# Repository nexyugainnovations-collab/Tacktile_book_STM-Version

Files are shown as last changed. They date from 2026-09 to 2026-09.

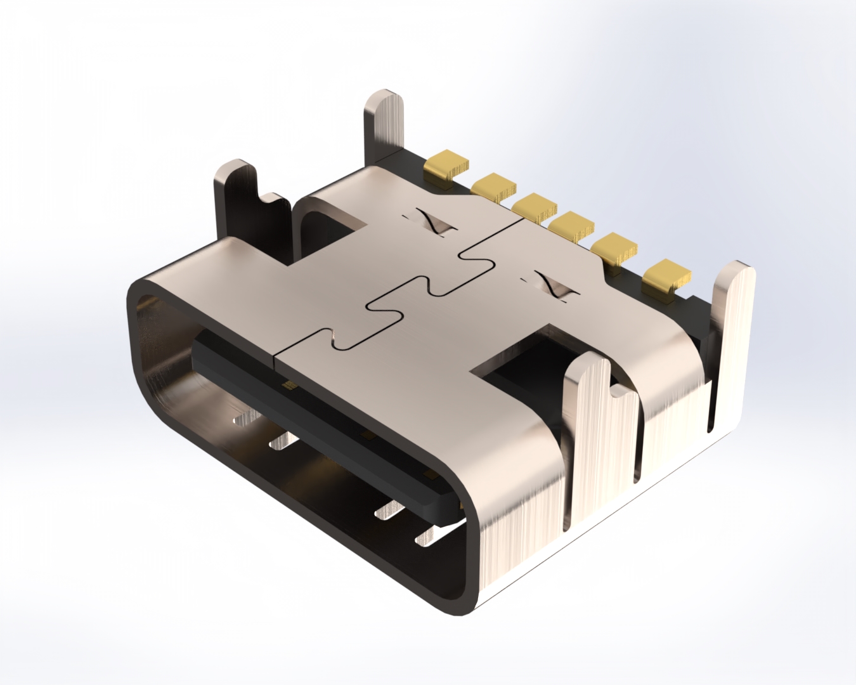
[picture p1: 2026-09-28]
3D models/USB Connector Type C female 6pin/USB Connector Type C female 6pin.jpg

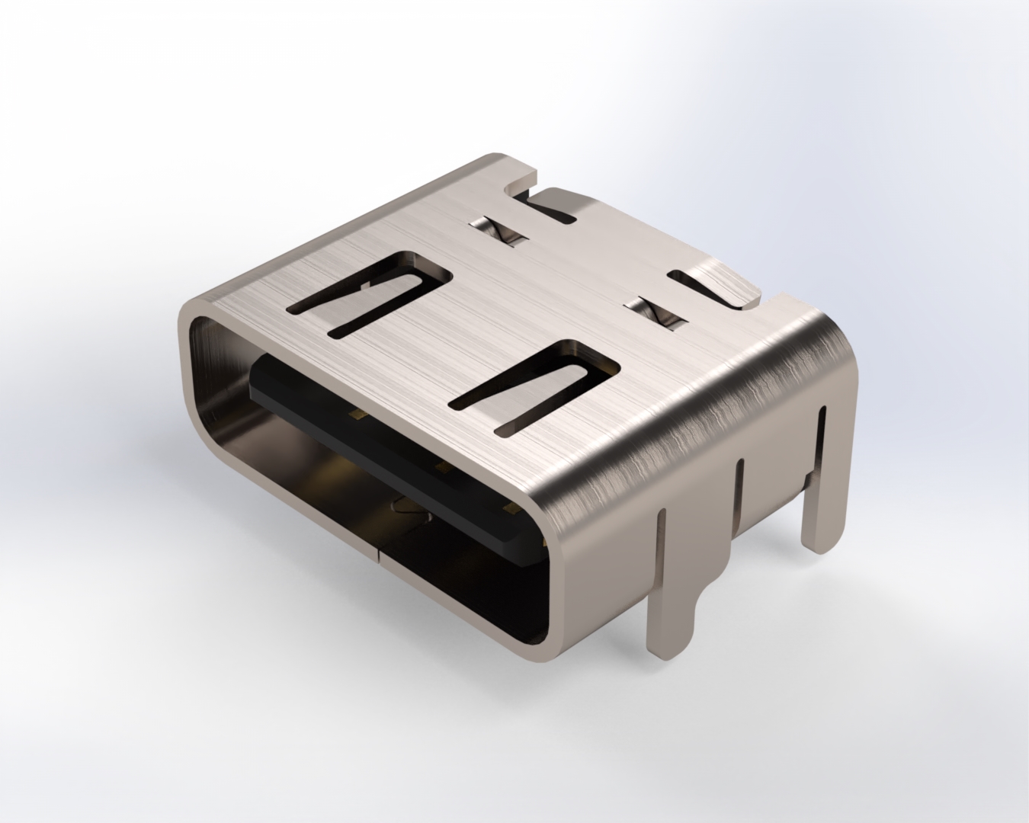
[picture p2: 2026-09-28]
3D models/USB Connector Type C female 6pin/USB Connector Type C female 6pin (2).jpg

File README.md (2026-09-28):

# Tacktile Book STM (v1.0)

STM32-based hardware design for the Tacktile book, an interactive tactile book that plays audio in response to touch. This repository contains the PCB design files and the audio content used by the device.

Developed by **Nexyuga Innovations**.

## Contents

| Folder | Description |
|---|---|
| pcb/ | Schematic and board layout source files |
| gerber/ | Fabrication outputs (Gerbers, drill files) |
| bom/ | Bill of materials |
| audio/ | Audio files used by the device |
| docs/ | Datasheets, notes and images |

Folder names may differ slightly from the actual layout. Update the table to match the repository.

## Hardware

- **Microcontroller:** STM32 (part number: TBD)
- **PCB design tool:** TBD
- **Audio:** stored audio played back through an amplifier and speaker
- **Input:** touch or button input from the tactile pages

## Getting Started

Clone the repository:

    git clone https://github.com/nexyugainnovations-collab/Tacktile_book_STM-Version.git
    cd Tacktile_book_STM-Version

1. Open the project file from the pcb/ folder in your PCB design tool.
2. To manufacture the board, send the contents of gerber/ to a PCB fabricator and use bom/ for component sourcing.
3. Flash the firmware to the STM32 using STM32CubeProgrammer or an ST-Link.

## Version History

| Version | Notes |
|---|---|
| v1.0 | Initial release: PCB and audio files |

## Contributors

- Pravin Balu ([*****](https://github.com/*****))
- Nithilan Saravanan ([@nithilan0710](https://github.com/nithilan0710))
- Nexyuga Innovations

## License

Proprietary. All rights reserved by Nexyuga Innovations.

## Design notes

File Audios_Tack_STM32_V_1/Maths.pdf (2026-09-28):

1 -------> One

2 -------> Two

4 -------> Four

3 -------> Three

Numbers
0 -------> Zero

5 -------> Five

7 -------> Seven

8 -------> Eight

10 -------> Ten

9 -------> Nine

6 -------> Six

11 -------> Eleven

13 -------> Thirteen

14 -------> Fourteen

16 -------> Sixteen

15 -------> Fifteen

12 -------> Twelve

17 -------> Seventeen

19 -------> Nineteen

20 -------> Twenty

18 -------> Eighteen

Whole Numbers

Natural Numbers

+ ----- Addition

– ----- Subtraction

x ----- Multiplication

----- Division

Operations

= ----- Equal to

% ----- Percentange

Addition

2 + 2 = 4

3 + 3 = 6

4 + 4 = 8

5 + 5 = 10

6 + 6 = 12

1 + 1 = 2

4 - 2 = 2

6 - 3 = 3

8 - 4 = 4

10 - 5 = 5

12 - 6 = 6

Subtraction
2 - 1 = 1

### 2 x 2 = 4

### 6 x 2 = 12

### 3 x 2 = 6

### 4 x 2 = 8

### 5 x 2 = 10

Multiplication

### 1 x 2 = 2

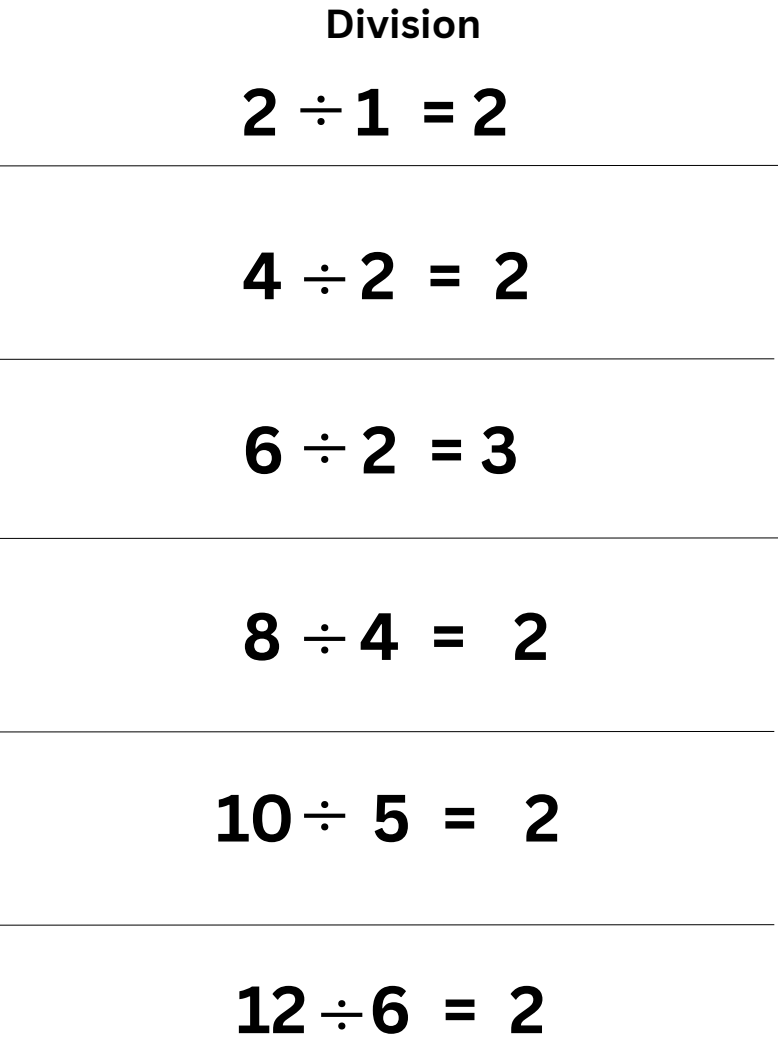
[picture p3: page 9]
Division 2 1 = 2

> → Greater than

< → Less than

5 > 3

2 < 5

3 < 10

8 > 6

Ascending Order

1 , 2 , 3 , 4 , 5 , 6

2 , 4 , 6 , 8 , 9 , 10

8 , 7 , 6 , 5 , 4 , 3

Descending Order

12 , 6 , 4 , 3 , 2 , 0

Odd Numbers

1 3 5 7 9

11 13 15 17

Even Numbers

10 12 14 16

2 4 6 8

Number Sequence
1, 2, 3, 4, 5, ___

6, 7, 8, 9, 10, ___

2, 4, 6, 8, 10, ___

1, 3, 5, 7, 9, ___

5, 10, 15, 20, 25, ___

10,20,30,40,___

1 → We have one head.

2 → We have two eyes.

4 → A chair has four legs.

3 → A triangle has three sides.

6 → A cube has six sides.

Counting Around Us

5 → Five fingers on one hand.

7 → The world has seven wonders.

8 → A spider has eight legs.

10 → We have ten fingers.

9 → Navaratri lasts nine days.

12 → A year has twelve months..

11 → Cricket has eleven players.

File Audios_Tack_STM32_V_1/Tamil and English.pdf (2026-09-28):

உ | யி ெரழுத்துக்கள்

ஆ → ஆடு

இ → இல்லம்

ஈ → ஈட்டி

உ → உ | டை
அ → அம் | மா
ஊ → ஊஞ்சல் | 1

ஏ → ஏ | ணி

ஐ → ஐந்து

ஒ → ஒட்டகம்

ஓ → ஓடம்

எ → எலி

ஔ → ஔ | வை யார் | 2

ஆய்த எழுத்து

ஃ

எடுத்துக் | கா ட்டு: அஃது, எஃகு

ங் → நுங்கு

ச் → பூச் | சி

ஞ் → அஞ்சல்

# ட் → கட் டை

மெ ய்ெயழுத்துகள்

ண் → கண்

க் → பூக்கள்

ந் → ஆந் | தை

ப் → கப்பல்

ய் → | நா ய்
ர் → | தே ர்
த் → கத் | தி
ம் → | மா ம்பழம்

வ் → | செ வ்வகம்
ழ் → | வா ழ்த்து
ற் → கற் | றா ைழ
ன் → | தெ ன்ைன

ல் → கல்

ள் → பள் | ளி

க் + ஆ = | கா
க் + இ = | கி

க் + உ = கு

க் + ஊ = கூ

உ | யி ர்ெமய் எழுத்துகள்

க் + ஈ = கீ

க் + அ =க

க் + ஏ = | கே
க் + ஐ = | கை
க் + ஓ = | கோ
க் + ஔ = | கௌ
க் + ஒ = | கொ
க் + எ = | கெ

2 → இரண்டு

3 → மூன்று

5 → ஐந்து

# 4 → நா ன்கு

1 → ஒன்று

எண்கள்
0 → சு | ழி யம்

8 → எட்டு

9 → ஒன்பது

# 11 → ப தி னொ ன்று

10 → பத்து

7 → ஏழு

6 → ஆறு

14 → ப | தி னா ன்கு
15 → ப | தி னை ந்து
18 → ப | தி னெ ட்டு
17 → ப | தி னே ழு
13 → ப | தி மூன்று
12 → பன் | னி ரண்டு

20 → இருபது

19 → பத் | தொ ன்பது

## English

A a → A for Apple

B b → B for Banana

C c → C for Carrot

D d → D for Dog

E e → E for Egg

F f → F for Fish

Alphabets

G g → G for Grapes

H h → H for Hat

I i → I for Ice Cream

J j → J for Jug

K k → K for Key

L l → L for Lion | 15

M m → M for Mango

N n → N for Nest

O o → O for Orange

P p → P for Parrot

Q q → Q for Queen

R r → R for Rabbit | 16

S s → S for School

T t → T for Toy

U u → U for Umbrella

V v → V for Van

W w → W for Watch

X x → X for Xmas | 17

Y y → Y for Yarn

Z z → Z for Zip

Vowels

A E I O U

Consonants

B C D F G H J K L M N P Q R S T V W X Y Z

am → I am Tara.

an → An ant.

at → I am at home.

do → Do your homework.

go → Go to school.

hi → Hi, friend!

Two Letter Words in → Sit in the classroom.

it → It is my bag.

my → My name is Kavi.

No → No shouting in class.

up → Get up from your seat.

me → Give it to me.

and → You and me.

run → Run fast.

eat → Eat your food.

get → Get the ball.

cry → I cry when I feel sad.

she → She is happy.

Three-Letter Words

you → You sit here.

put → Put it here.

use → Use this pen.

win → I win the game.

ask → Ask a question.

say → Say your name.

Eat → Eat your food.

Read → Read a book.

Drink → Drink water.

Write → Write your homework.

Walk → Walk slowly.

Open → Open the door.

Action Words

Close → Close the gate.

Play → Play well.

Sleep → Sleep well.

Talk → Talk politely.

Take → Take the pen.

Listen → Listen to me.

We → We are friends.

This → This is my pen.

That → That is my book.

Here → Sit here with me.

There → Go there.

Sight Words

are → We are friends.

I wake up early.

I brush my teeth.

I take a bath.

I eat a healthy breakfast.

I go to school.

Daily Routine

I learn and play. | 26

I come back home.

I do my homework.

I eat dinner.

I sleep at night.

Again, I wake up early..

Rhymes

Twinkle Twinkle Little Star

Twinkle, twinkle, little star, How I wonder what you are! Up above the world so high, Like a diamond in the sky.

Jack and Jill
Jack and Jill went up the hill, To fetch a pail of water.
Jack fell down and broke his crown, And Jill came tumbling after. Up Jack got and home did trot, As fast as he could caper. He went to bed to mend his head, With vinegar and brown paper.

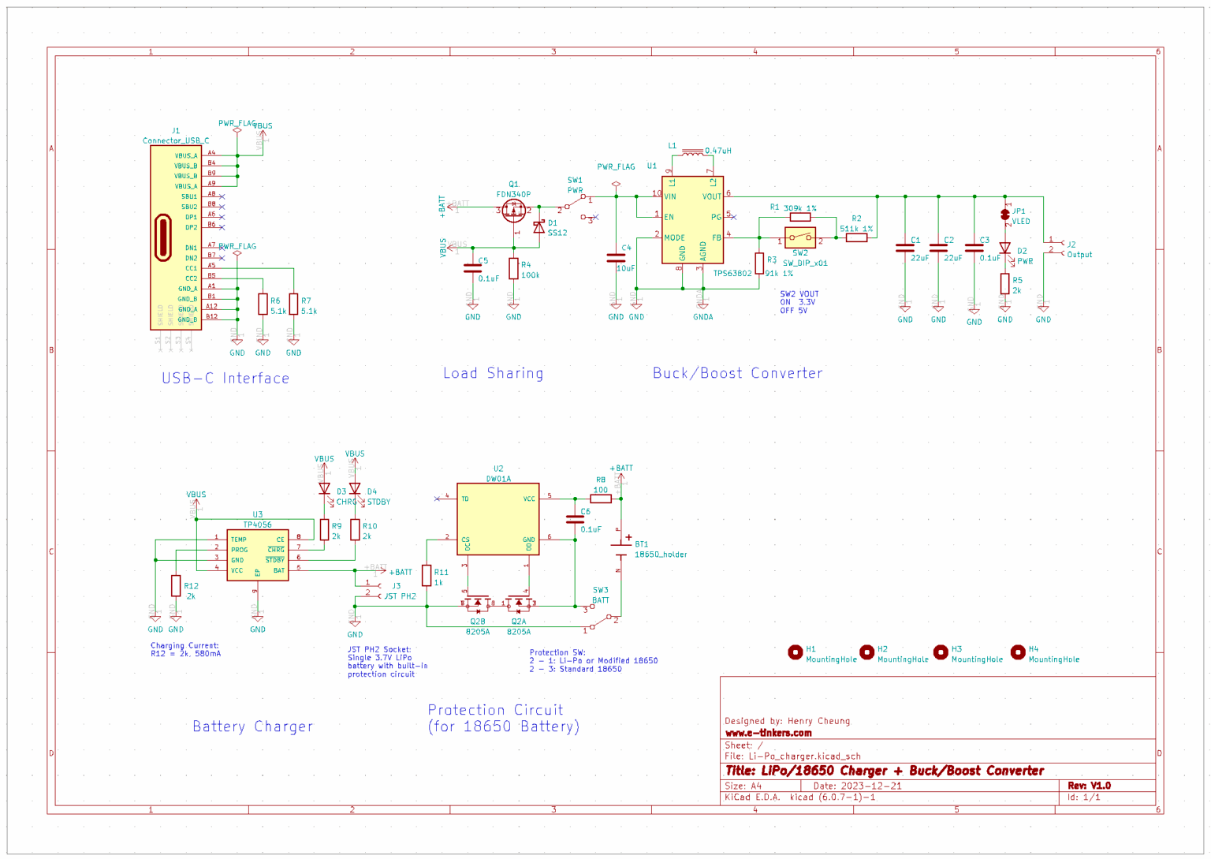
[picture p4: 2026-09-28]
References/18650_charger_with_load_sharing_and_buck_boost_converter_schematic-1536x1089.png

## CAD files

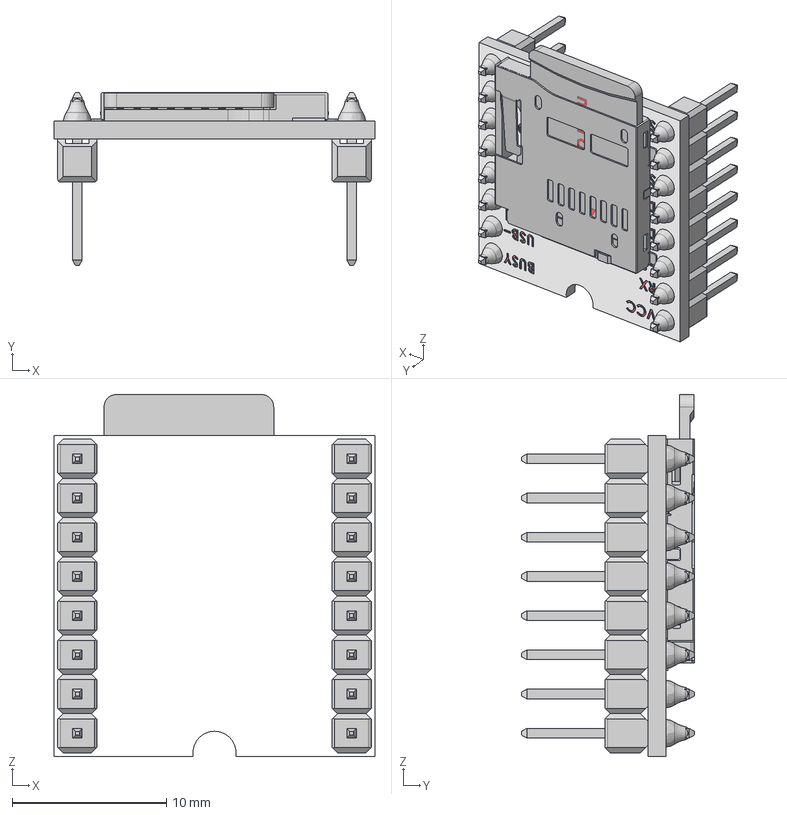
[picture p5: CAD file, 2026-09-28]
3D models/dfplayer-mini-3.snapshot.1/DFPlayer Mini Assem v1.step
20.8 x 11.2 x 23.5 mm
DFPlayer Mini PCB
CD card slot
Micro sd card
11_20mm pin x 16
Pin Header 1x12 TH Pitch 2 x 16
solder x 16

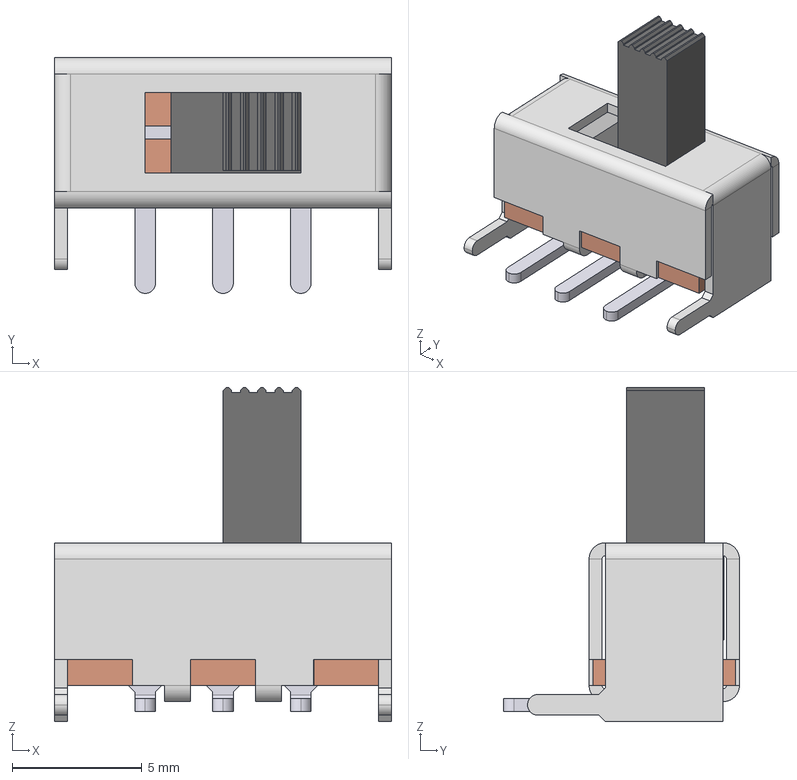
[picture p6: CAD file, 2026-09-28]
3D models/Slide Switch - SS12F23.stp
13.0 x 9.10 x 12.9 mm
User Library-SLIDE SWITCH SS12F23_SLIDE SWITCH SS12F23 Contato
User Library-SLIDE SWITCH SS12F23_SLIDE SWITCH SS12F23 ATUADOR
User Library-SLIDE SWITCH SS12F23_SLIDE SWITCH SS12F23 LATERAL x 2
User Library-SLIDE SWITCH SS12F23_SLIDE SWITCH SS12F23 CENTRAL
User Library-SLIDE SWITCH SS12F23_SLIDE SWITCH SS12F23 PCB
User Library-SLIDE SWITCH SS12F23_SLIDE SWITCH SS12F23 CAPA

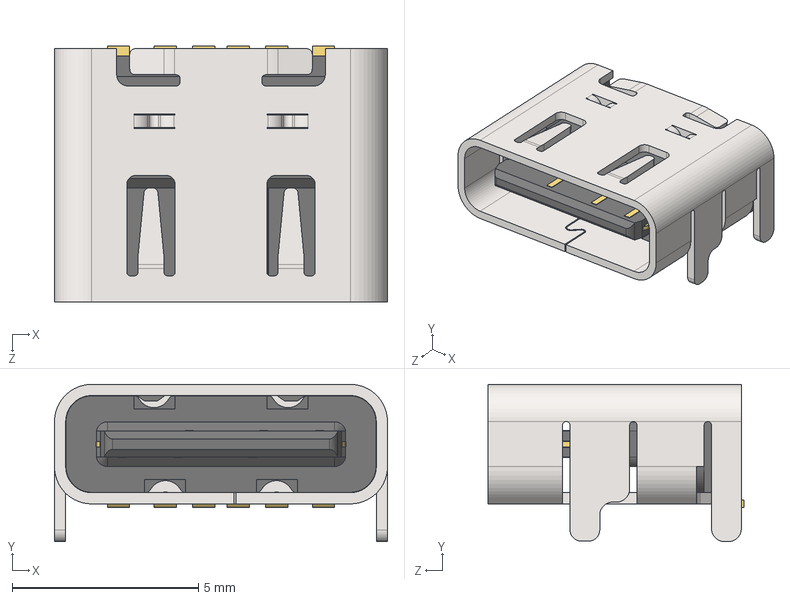
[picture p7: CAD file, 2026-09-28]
3D models/USB Connector Type C female 6pin/USB Connector Type C female 6pin.STEP
8.94 x 4.22 x 6.87 mm

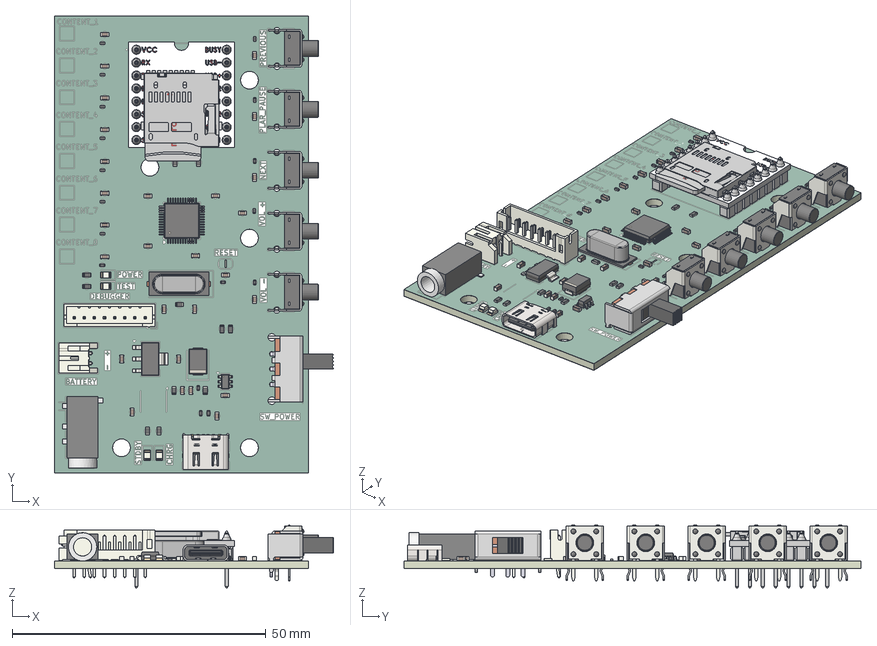
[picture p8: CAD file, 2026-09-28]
board_step_file/Tack_STM32_V_1.step
55.0 x 90.0 x 12.4 mm
C_0603_1608Metric x 27
R_0402_1005Metric x 17
DFPlayer Mini PCB
CD card slot
Micro sd card
11_20mm pin x 16
Pin Header 1x12 TH Pitch 2 x 16
solder x 16
R_0603_1608Metric x 11
LED_0805_2012Metric x 4
D_SMB
User Library-SLIDE SWITCH SS12F23_SLIDE SWITCH SS12F23 Contato
User Library-SLIDE SWITCH SS12F23_SLIDE SWITCH SS12F23 ATUADOR
User Library-SLIDE SWITCH SS12F23_SLIDE SWITCH SS12F23 LATERAL x 2
User Library-SLIDE SWITCH SS12F23_SLIDE SWITCH SS12F23 CENTRAL
User Library-SLIDE SWITCH SS12F23_SLIDE SWITCH SS12F23 PCB
User Library-SLIDE SWITCH SS12F23_SLIDE SWITCH SS12F23 CAPA
SW_Tactile_SPST_Angled_PTS645Vx58-2LFS x 5
Crystal_SMD_HC49-SD
TRRS20153
SOT-223
LQFP-48_7x7mm_P0.5mm
SOT-23-6
USB Connector Type C female 6pin
JST_PH_B8B-PH-K_1x08_P2.00mm_Vertical
JST_PH_S2B-PH-K_1x02_P2.00mm_Horizontal
Tack_STM32_V_1_silkscreen x 2
Tack_STM32_V_1_soldermask x 2
Tack_STM32_V_1_PCB

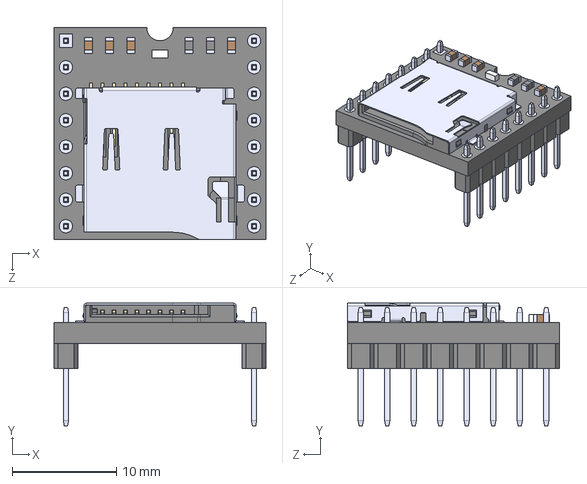
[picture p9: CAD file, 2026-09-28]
DFR0299/DFR0299.step
20.3 x 11.8 x 20.3 mm

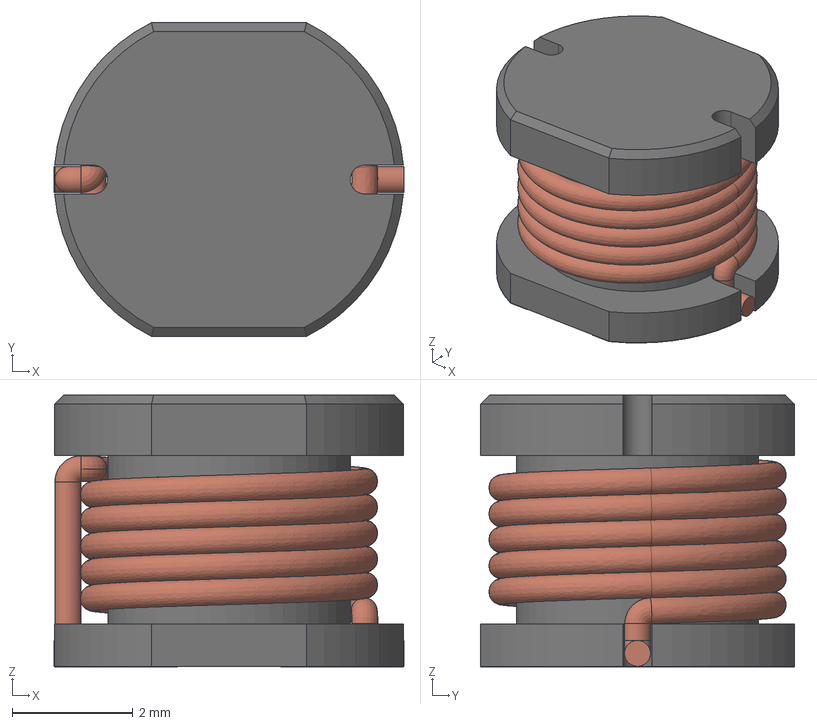
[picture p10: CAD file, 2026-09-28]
3D models/SMD_Inductor_CD54.step
5.80 x 5.20 x 4.50 mm

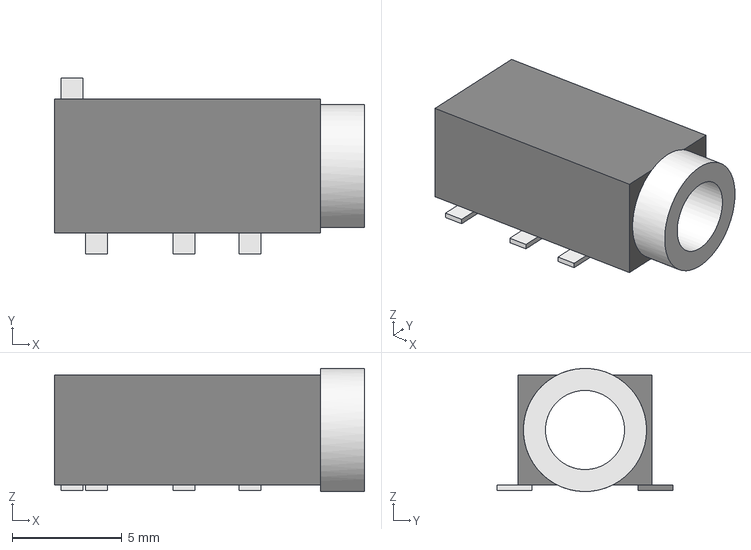
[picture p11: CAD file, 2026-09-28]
3D models/TRRS20153.step
14.1 x 8.00 x 5.60 mm

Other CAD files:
3D models/USB Connector Type C female 6pin/USB Connector Type C female 6pin.SLDPRT

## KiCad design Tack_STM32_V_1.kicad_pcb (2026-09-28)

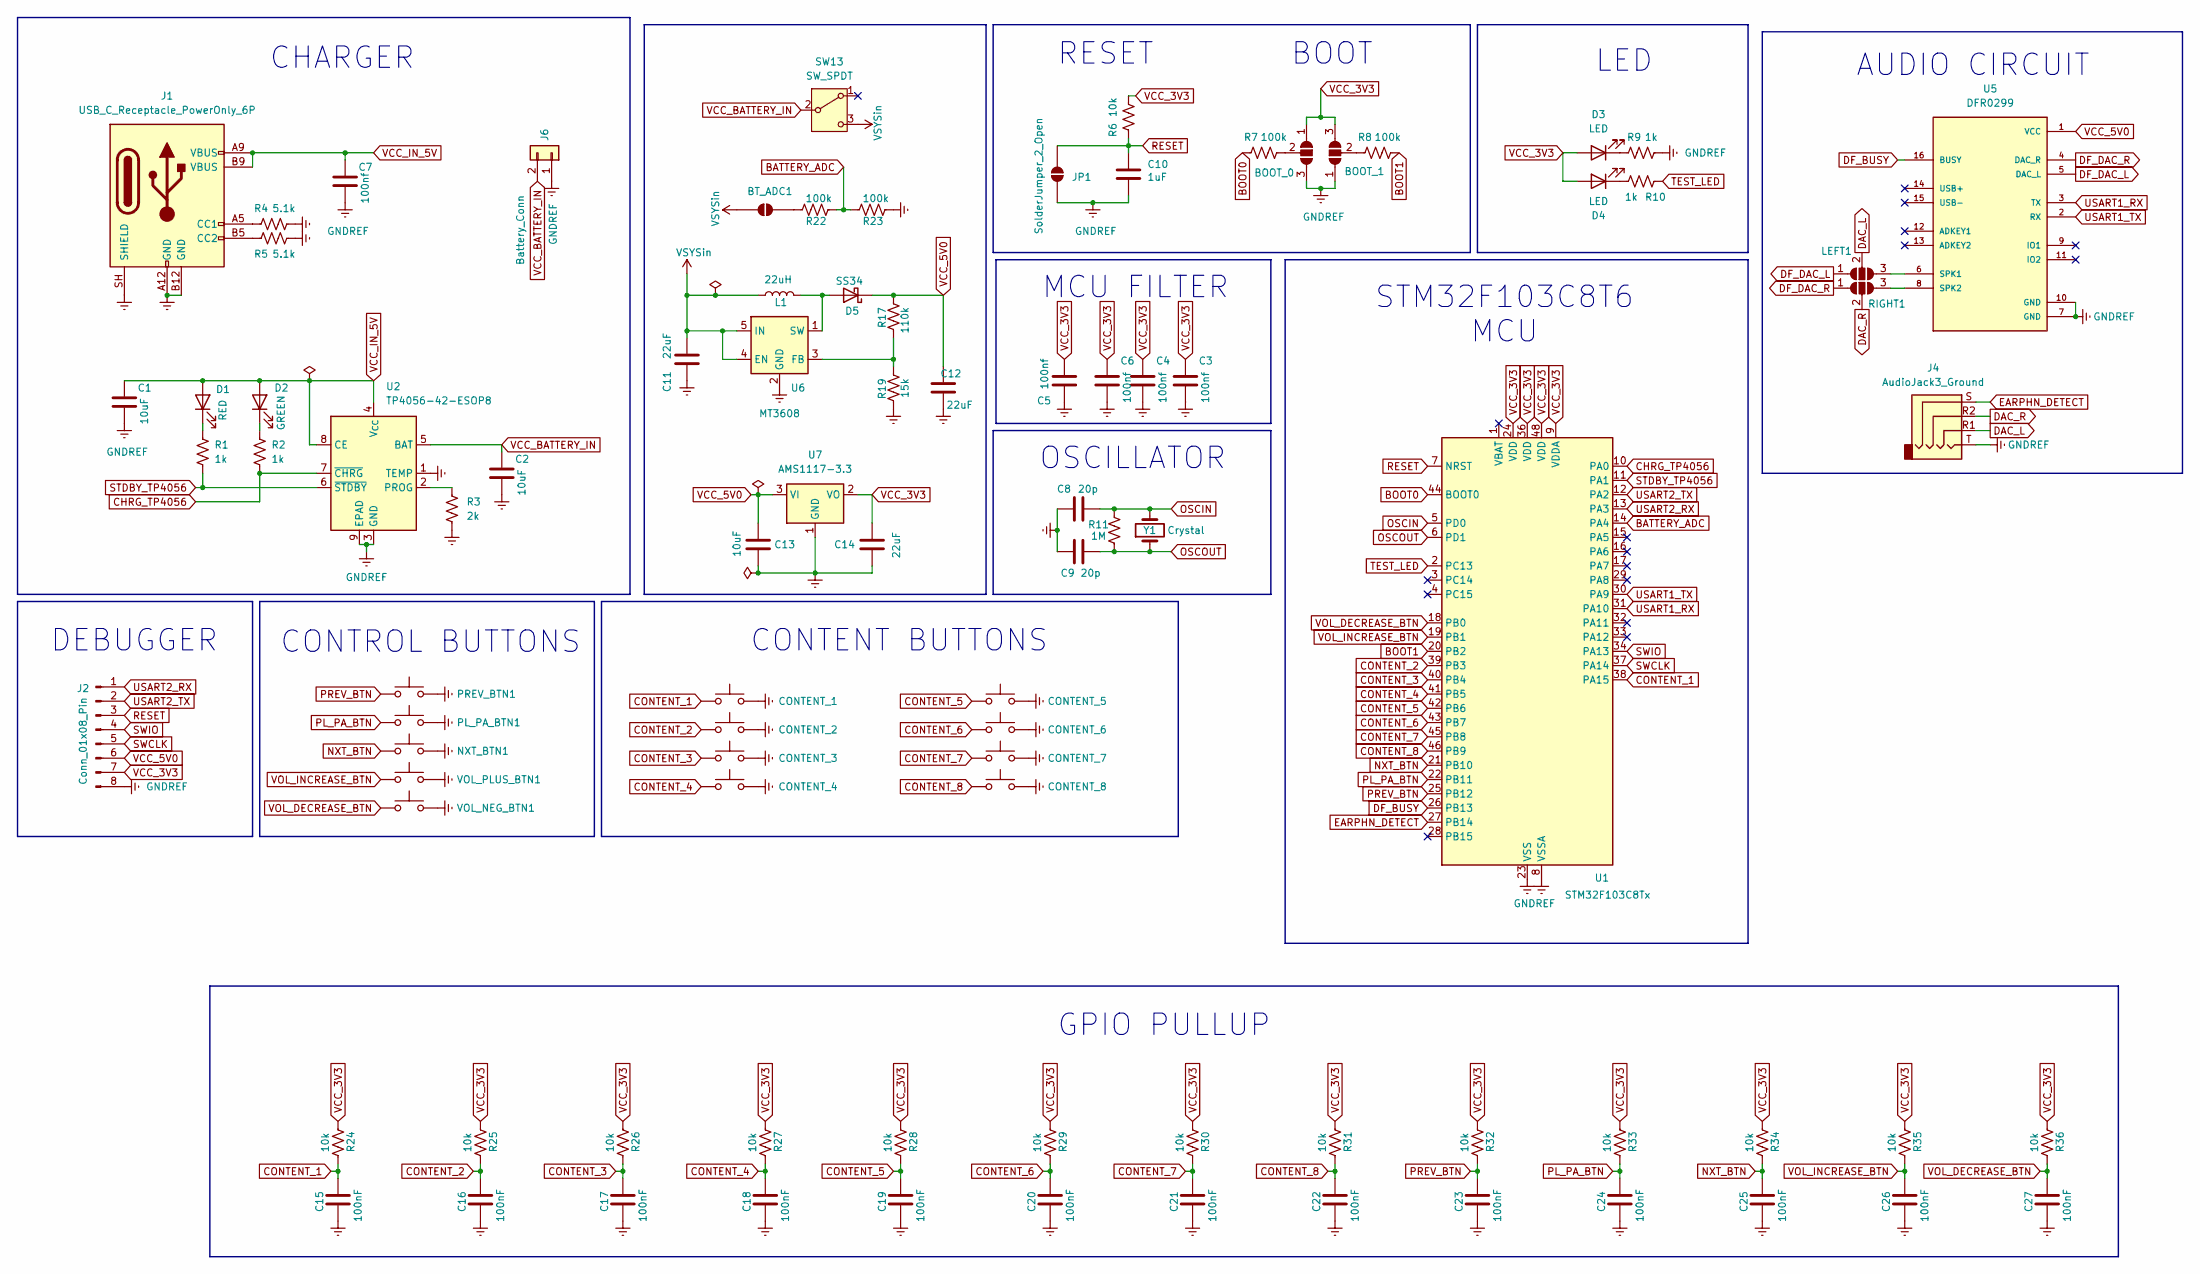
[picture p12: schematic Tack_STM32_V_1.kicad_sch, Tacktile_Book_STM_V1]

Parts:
BOOT_0, BOOT_1: SolderJumper_3_Open; SolderJumper-3_P1.3mm_Open_Pad1.0x1.5mm
BT_ADC1: SolderJumper_2_Open; SolderJumper-2_P1.3mm_Open_RoundedPad1.0x1.5mm
C1, C2, C13: 10uF; C_0603_1608Metric_Pad1.08x0.95mm_HandSolder
C3, C4, C5, C6, C7: 100nf; C_0603_1608Metric_Pad1.08x0.95mm_HandSolder
C8, C9: 20p; C_0603_1608Metric_Pad1.08x0.95mm_HandSolder
C10: 1uF; C_0603_1608Metric_Pad1.08x0.95mm_HandSolder
C11, C12, C14: 22uF; C_0603_1608Metric_Pad1.08x0.95mm_HandSolder
C15, C16, C17, C18, C19, C20, C21, C22, C23, C24, C25, C26, C27: 100nF; C_0603_1608Metric_Pad1.08x0.95mm_HandSolder
CONTENT_1: CONTENT_1; SW_CONTENT_2.5mm
CONTENT_2: CONTENT_2; SW_CONTENT_2.5mm
CONTENT_3: CONTENT_3; SW_CONTENT_2.5mm
CONTENT_4: CONTENT_4; SW_CONTENT_2.5mm
CONTENT_5: CONTENT_5; SW_CONTENT_2.5mm
CONTENT_6: CONTENT_6; SW_CONTENT_2.5mm
CONTENT_7: CONTENT_7; SW_CONTENT_2.5mm
CONTENT_8: CONTENT_8; SW_CONTENT_2.5mm
D1: RED; LED_0805_2012Metric_Pad1.15x1.40mm_HandSolder
D2: GREEN; LED_0805_2012Metric_Pad1.15x1.40mm_HandSolder
D3, D4: LED; LED_0805_2012Metric_Pad1.15x1.40mm_HandSolder
D5: SS34; D_SMB
J1: USB_C_Receptacle_PowerOnly_6P; USB_C_Receptacle_HRO_TYPE-C-31-M-17
J2: Conn_01x08_Pin; JST_PH_B8B-PH-K_1x08_P2.00mm_Vertical
J4: AudioJack3_Ground; Jack_3.5mm_PJ320D_Horizontal
J6: Battery_Conn; JST_EH_S2B-EH_1x02_P2.50mm_Horizontal
JP1: SolderJumper_2_Open; SolderJumper-2_P1.3mm_Open_RoundedPad1.0x1.5mm
L1: 22uH; L_Inductor 22uH – 5.2×5.8×4.5mm – CD54 – SMD
LEFT1: SolderJumper_3_Open; SolderJumper-3_P1.3mm_Open_Pad1.0x1.5mm
NXT_BTN1: NXT_BTN; SW_Tactile_SPST_Angled_PTS645Vx58-2LFS
PL_PA_BTN1: PL_PA_BTN; SW_Tactile_SPST_Angled_PTS645Vx58-2LFS
PREV_BTN1: SW_Tactile_SPST_Angled_PTS645Vx58-2LFS
R1, R2, R9, R10: 1k; R_0603_1608Metric_Pad0.98x0.95mm_HandSolder
R3: 2k; R_0603_1608Metric_Pad0.98x0.95mm_HandSolder
R4, R5: 5.1k; R_0603_1608Metric_Pad0.98x0.95mm_HandSolder
R6, R24, R25, R26, R27, R28, R29, R30, R31, R32, R33, R34, R35, R36: 10k; R_0402_1005Metric_Pad0.72x0.64mm_HandSolder
R7, R8, R22, R23: 100k; R_0603_1608Metric_Pad0.98x0.95mm_HandSolder
R11: 1M; R_0603_1608Metric_Pad0.98x0.95mm_HandSolder
R17: 110k; R_0603_1608Metric_Pad0.98x0.95mm_HandSolder
R19: 15k; R_0402_1005Metric_Pad0.72x0.64mm_HandSolder
RIGHT1: SolderJumper_3_Open; SolderJumper-3_P1.3mm_Open_Pad1.0x1.5mm
SW13: SW_SPDT; SS12F23G5 Mini SPDT Slide Switch Right Angle
U1: STM32F103C8Tx; LQFP-48_7x7mm_P0.5mm
U2: TP4056-42-ESOP8; SOIC-8-1EP_3.9x4.9mm_P1.27mm_EP2.41x3.3mm_ThermalVias
U5: DFR0299; MODULE_DFR0299
U6: MT3608; SOT-23-6
U7: AMS1117-3.3; SOT-223-3_TabPin2
VOL_NEG_BTN1: VOL_NEG_BTN; SW_Tactile_SPST_Angled_PTS645Vx58-2LFS
VOL_PLUS_BTN1: VOL_PLUS_BTN; SW_Tactile_SPST_Angled_PTS645Vx58-2LFS
Y1: Crystal; Crystal_SMD_HC49-SD

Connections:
BATTERY_ADC: R22.1, R23.2, U1.14 (PA4)
BOOT0: R7.1, U1.44 (BOOT0)
BOOT1: R8.2, U1.20 (PB2)
CHRG_TP4056: R2.2, U1.10 (PA0), U2.7 (~CHRG)
CONTENT_1: C15.1, CONTENT_1.1, R24.2, U1.38 (PA15)
CONTENT_2: C16.1, CONTENT_2.1, R25.2, U1.39 (PB3)
CONTENT_3: C17.1, CONTENT_3.1, R26.2, U1.40 (PB4)
CONTENT_4: C18.1, CONTENT_4.1, R27.2, U1.41 (PB5)
CONTENT_5: C19.1, CONTENT_5.1, R28.2, U1.42 (PB6)
CONTENT_6: C20.1, CONTENT_6.1, R29.2, U1.43 (PB7)
CONTENT_7: C21.1, CONTENT_7.1, R30.2, U1.45 (PB8)
CONTENT_8: C22.1, CONTENT_8.1, R31.2, U1.46 (PB9)
DAC_L: J4.R1, LEFT1.2 (C)
DAC_R: J4.R2, RIGHT1.2 (C)
DF_BUSY: U1.26 (PB13), U5.16 (BUSY)
DF_DAC_L: LEFT1.1 (A), U5.5 (DAC_L)
DF_DAC_R: RIGHT1.1 (A), U5.4 (DAC_R)
EARPHN_DETECT: J4.S, U1.27 (PB14)
GNDREF: BOOT_0.3 (B), BOOT_1.1 (A), C1.2, C2.2, C3.2, C4.2, C5.1, C6.2, C7.2, C8.1, C9.2, C10.2, C11.1, C12.1, C13.2, C14.2, C15.2, C16.2, C17.2, C18.2, C19.2, C20.2, C21.2, C22.2, C23.2, C24.2, C25.2, C26.2, C27.2, CONTENT_1.2, CONTENT_2.2, CONTENT_3.2, CONTENT_4.2, CONTENT_5.2, CONTENT_6.2, CONTENT_7.2, CONTENT_8.2, J1.A12 (GND), J1.B12 (GND), J1.SH (SHIELD), J2.8, J4.T, J6.1, JP1.1 (A), NXT_BTN1.2, PL_PA_BTN1.2, PREV_BTN1.2, R3.2, R4.2, R5.1, R9.2, R19.1, R23.1, U1.8 (VSSA), U1.23 (VSS), U1.35 (VSS), U1.47 (VSS), U2.1 (TEMP), U2.3 (GND), U2.9 (EPAD), U5.7 (GND), U5.10 (GND), U6.2 (GND), U7.1 (GND), VOL_NEG_BTN1.2, VOL_PLUS_BTN1.2
NXT_BTN: C25.1, NXT_BTN1.1, R34.2, U1.21 (PB10)
unnamed: BOOT_0.2 (C), R7.2
unnamed: BOOT_1.2 (C), R8.1
unnamed: BT_ADC1.1 (A), R22.2
unnamed: D1.1 (K), R1.1
unnamed: D2.1 (K), R2.1
unnamed: D3.1 (K), R9.1
unnamed: D4.1 (K), R10.2
unnamed: D5.2 (A), L1.2, U6.1 (SW)
unnamed: J1.A5 (CC1), R4.1
unnamed: J1.B5 (CC2), R5.2
unnamed: LEFT1.3 (B), U5.6 (SPK1)
unnamed: RIGHT1.3 (B), U5.8 (SPK2)
unnamed: R3.1, U2.2 (PROG)
unnamed: R17.1, R19.2, U6.3 (FB)
OSCIN: C8.2, R11.2, U1.5 (PD0), Y1.2
OSCOUT: C9.1, R11.1, U1.6 (PD1), Y1.1
PL_PA_BTN: C24.1, PL_PA_BTN1.1, R33.2, U1.22 (PB11)
PREV_BTN: C23.1, PREV_BTN1.1, R32.2, U1.25 (PB12)
RESET: C10.1, J2.3, JP1.2 (B), R6.1, U1.7 (NRST)
STDBY_TP4056: R1.2, U1.11 (PA1), U2.6 (~STDBY)
SWCLK: J2.5, U1.37 (PA14)
SWIO: J2.4, U1.34 (PA13)
TEST_LED: R10.1, U1.2 (PC13)
USART1_RX: U1.31 (PA10), U5.3 (TX)
USART1_TX: U1.30 (PA9), U5.2 (RX)
USART2_RX: J2.1, U1.13 (PA3)
USART2_TX: J2.2, U1.12 (PA2)
VCC_3V3: BOOT_0.1 (A), BOOT_1.3 (B), C3.1, C4.1, C5.2, C6.1, C14.1, D3.2 (A), D4.2 (A), J2.7, R6.2, R24.1, R25.1, R26.1, R27.1, R28.1, R29.1, R30.1, R31.1, R32.1, R33.1, R34.1, R35.1, R36.1, U1.9 (VDDA), U1.24 (VDD), U1.36 (VDD), U1.48 (VDD), U7.2 (VO)
VCC_5V0: C12.2, C13.1, D5.1 (K), J2.6, R17.2, U5.1 (VCC), U7.3 (VI)
VCC_BATTERY_IN: C2.1, J6.2, SW13.2 (B), U2.5 (BAT)
VCC_IN_5V: C1.1, C7.1, D1.2 (A), D2.2 (A), J1.A9 (VBUS), J1.B9 (VBUS), U2.4 (V_{CC}), U2.8 (CE)
VOL_DECREASE_BTN: C27.1, R36.2, U1.18 (PB0), VOL_NEG_BTN1.1
VOL_INCREASE_BTN: C26.1, R35.2, U1.19 (PB1), VOL_PLUS_BTN1.1
VSYSin: BT_ADC1.2 (B), C11.2, L1.1, SW13.3 (C), U6.4 (EN), U6.5 (IN)

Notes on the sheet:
CONTROL BUTTONS
CONTENT BUTTONS
RESET
OSCILLATOR
LED
CHARGER
BOOT
GPIO PULLUP
MCU FILTER
DEBUGGER
AUDIO CIRCUIT
STM32F103C8T6 MCU

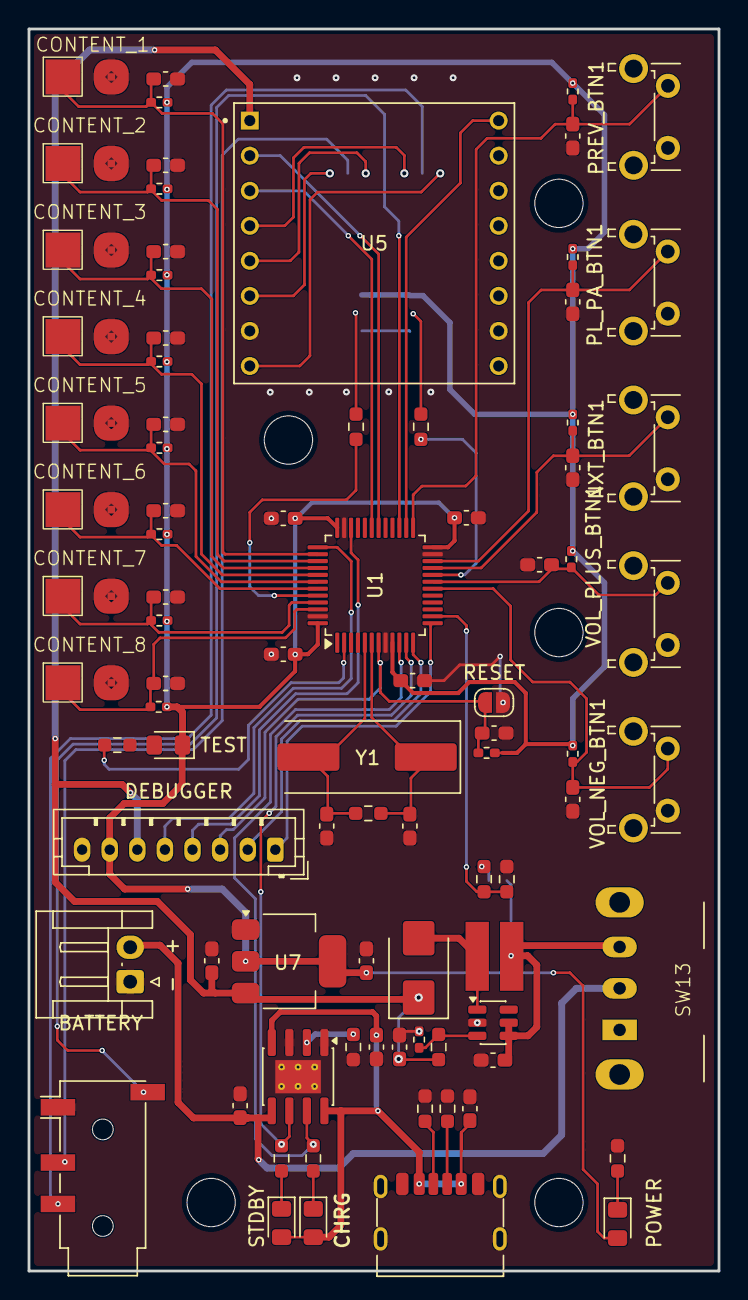
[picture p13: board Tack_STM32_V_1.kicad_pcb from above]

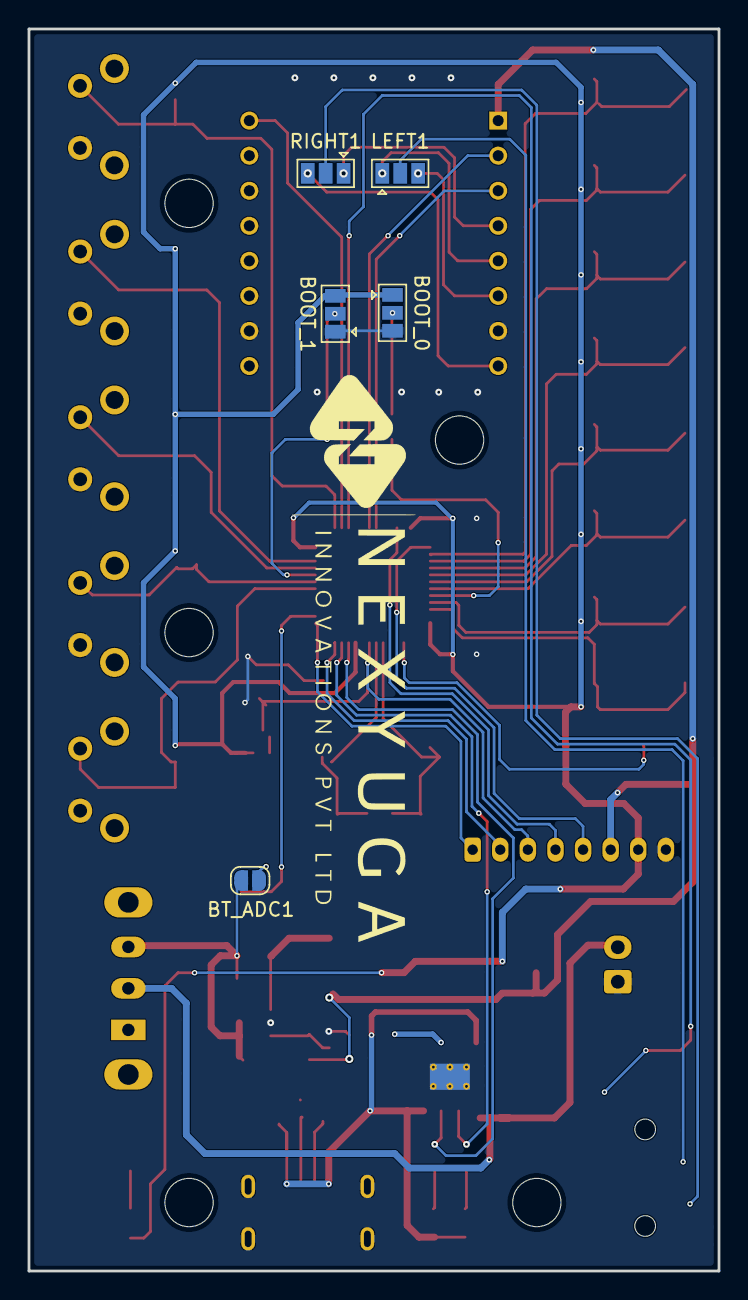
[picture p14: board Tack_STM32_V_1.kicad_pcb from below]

Board: 2 copper layers, 50.0 x 90.0 mm, 91 parts (5 on the bottom side), 54 nets.
